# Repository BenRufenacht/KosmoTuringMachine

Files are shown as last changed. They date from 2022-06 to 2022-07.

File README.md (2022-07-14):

# Kosmo Turing Machine

This is the Turing Machine Eurorack module by Tom Whitwell converted into Kosmo format.

<p align="center">
  
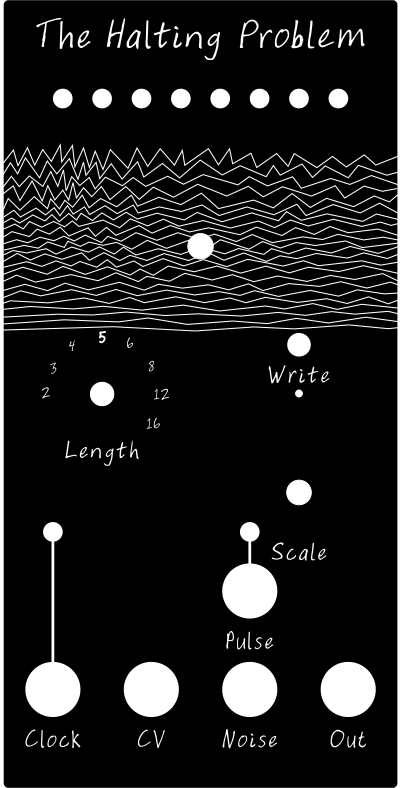
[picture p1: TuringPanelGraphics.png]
  
  
</p>

<p align="center">
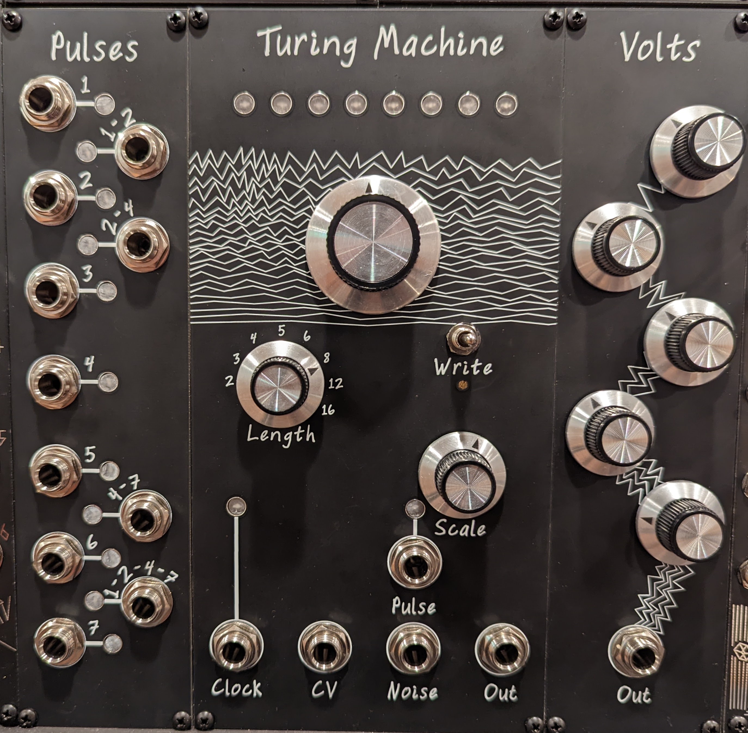
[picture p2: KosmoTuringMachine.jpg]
  
</p>

Here is the description of the module from Tom Whitwell:

Since it was launched in June 2012, the Turing Machine has become one of the most popular Eurorack DIY projects. It is a random looping sequencer that spits out basslines and melodies. It generates strings of random voltages that can be locked into looping sequences. 
These sequences can be allowed to slip, changing gradually over time. This module was inspired by the long history of shift register pseudorandom synth circuits, including the Triadex Muse, Buchla 266 Source of Uncertainly and Grant Richter’s Noisering.

[This video explains how the Turing Machine works.](https://www.youtube.com/watch?v=Le26BIqB8Y8)  

The 2016 revised Turing Machine has many improvements:  
- Rotary loop length switch 
- Pulse out
- Two boards, includes Backpack circuit to drive expanders (compatible with old Music Thing expanders)  
- Easier to build: a larger PCB in the same width, clock and noise circuits are more robust
- Noise level trimmer & reduced voltage in noise circuit to make circuit more robust with different noise transistors 
- Compatible with existing expanders 

[Schematic](https://github.com/TomWhitwell/TuringMachine/blob/master/Collateral/PDF%20Schematics/TuringMachine2_Schematic_May2016.pdf)

Status:   
July 2022 - Boards were manufactured and tested. Updates have been made to the main board and panel, but these updates have not been tested.

License:  
[CC-BY-SA](https://creativecommons.org/licenses/by-sa/3.0/)

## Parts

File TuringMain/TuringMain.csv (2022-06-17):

Source: | C:\Users\Walter\Documents\GitHub\KosmoTuringMachine\TuringMain\TuringMain.kicad_sch
Date: | 6/17/2022 11:51:15 AM
Tool: | Eeschema (6.0.5)
Generator: | C:\Program Files\KiCad\6.0\bin\scripting\plugins/bom_csv_grouped_by_value.py
Component Count: | 108
Individual Components:
Item | Qty | Reference(s) | Value | LibPart | Footprint | Datasheet | SKU | Vendor
 |  | AND_1 | 4081 | TuringBack-eagle-import:4081N | TuringBack:DIL14
 |  | AND_2 | 4081 | TuringBack-eagle-import:4081N | TuringBack:DIL14
 |  | BUFFER1 | 4050 | TuringBack-eagle-import:4050N | TuringBack:DIL16
 |  | BUFFER2 | 4050 | TuringBack-eagle-import:4050N | TuringBack:DIL16
 |  | C1 | 100n | TuringFront-eagle-import:C-EU050-024X044 | TuringFront:C050-024X044
 |  | C2 | 100n | TuringFront-eagle-import:C-EU050-024X044 | TuringFront:C050-024X044
 |  | C3 | 100n | TuringFront-eagle-import:C-EU050-024X044 | TuringFront:C050-024X044
 |  | C4 | 100n | TuringFront-eagle-import:C-EU050-024X044 | TuringFront:C050-024X044
 |  | C5 | 10uf | ao_symbols:CP | ao_tht:CP_Radial_D6.3mm_P2.50mm |  |  | Tayda
 |  | C6 | 10uf | ao_symbols:CP | ao_tht:CP_Radial_D6.3mm_P2.50mm |  |  | Tayda
 |  | C7 | 100n | TuringFront-eagle-import:C-EU050-024X044 | TuringFront:C050-024X044
 |  | C8 | 100n | TuringFront-eagle-import:C-EU050-024X044 | TuringFront:C050-024X044
 |  | C9 | 10n | TuringFront-eagle-import:C-EU050-024X044 | TuringFront:C050-024X044
 |  | C10 | 0.47uf | TuringFront-eagle-import:C-EU050-035X075 | TuringFront:C050-035X075
 |  | C11 | 0.47uf | TuringFront-eagle-import:C-EU050-035X075 | TuringFront:C050-035X075
 |  | C12 | 1n | TuringFront-eagle-import:C-EU050-024X044 | TuringFront:C050-024X044
 |  | C13 | 100n | TuringFront-eagle-import:C-EU050-024X044 | TuringFront:C050-024X044
 |  | C14 | 100n | TuringFront-eagle-import:C-EU050-024X044 | TuringFront:C050-024X044
 |  | C15 | 330pf | TuringFront-eagle-import:C-EU050-024X044 | TuringFront:C050-024X044
 |  | C16 | 100n | TuringFront-eagle-import:C-EU050-024X044 | TuringFront:C050-024X044
 |  | C17 | 1n | TuringFront-eagle-import:C-EU050-024X044 | TuringFront:C050-024X044
 |  | C18 | 0.47uf | TuringFront-eagle-import:C-EU050-035X075 | TuringFront:C050-035X075
 |  | C19 | 100n | TuringFront-eagle-import:C-EU050-024X044 | TuringFront:C050-024X044
 |  | C20 | 1n | TuringFront-eagle-import:C-EU050-024X044 | TuringFront:C050-024X044
 |  | C21 | 100n | TuringFront-eagle-import:C-EU050-024X044 | TuringFront:C050-024X044
 |  | C22 | 100n | TuringFront-eagle-import:C-EU050-024X044 | TuringFront:C050-024X044
 |  | C23 | 1n | TuringFront-eagle-import:C-EU050-024X044 | TuringFront:C050-024X044
 |  | C24 | 1n | TuringFront-eagle-import:C-EU050-024X044 | TuringFront:C050-024X044
 |  | C25 | 1n | TuringFront-eagle-import:C-EU050-024X044 | TuringFront:C050-024X044
 |  | C26 | 100n | TuringFront-eagle-import:C-EU050-024X044 | TuringFront:C050-024X044
 |  | C27 | 100n | TuringFront-eagle-import:C-EU050-024X044 | TuringFront:C050-024X044
 |  | CHANGE1 | 50k | ao_symbols:R_POT | ao_tht:Potentiometer_Alpha_RD901F-40-00D_Single_Vertical_centered | ~ |  | Tayda
 |  | CLK1 | LED5MM | ao_symbols:LED_green | ao_tht:LED_D5.0mm | ~ | A-1553 | Tayda
 |  | CLOCK1 | THONKICONNNEW | ao_symbols:AudioJack2 | ao_tht:Jack_6.35mm_PJ_629HAN | ~ | A-1121 | Tayda
 |  | CV_IN1 | THONKICONNNEW | ao_symbols:AudioJack2 | ao_tht:Jack_6.35mm_PJ_629HAN | ~ | A-1121 | Tayda
 |  | CV_OUT1 | THONKICONNNEW | ao_symbols:AudioJack2 | ao_tht:Jack_6.35mm_PJ_629HAN | ~ | A-1121 | Tayda
 |  | D2 | 1N4148 | TuringFront-eagle-import:SMALL_DIODEDO35-7 | TuringFront:DO35-7
 |  | GATES1 | MA08-2 | Connector_Generic:Conn_02x08_Odd_Even | Connector_IDC:IDC-Header_2x08_P2.54mm_Vertical | ~
 |  | IC1 | TL072P | TuringBack-eagle-import:TL072P | TuringBack:DIL08
 |  | IC2 | 78L09 | ao_symbols:L78L05_TO92 | Package_TO_SOT_THT:TO-92_Inline | http://www.st.com/content/ccc/resource/technical/document/datasheet/15/55/e5/aa/23/5b/43/fd/CD00000446.pdf/files/CD00000446.pdf/jcr:content/translations/en.CD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 | A-176 | Tayda
 |  | IC3 | 78L09 | ao_symbols:L78L05_TO92 | Package_TO_SOT_THT:TO-92_Inline | http://www.st.com/content/ccc/resource/technical/document/datasheet/15/55/e5/aa/23/5b/43/fd/CD00000446.pdf/files/CD00000446.pdf/jcr:content/translations/en.CD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 | A-176 | Tayda
 |  | J1 | Conn_01x10_Male | Connector:Conn_01x10_Male | Connector_PinHeader_2.54mm:PinHeader_1x10_P2.54mm_Vertical | ~
 |  | J2 | Conn_01x10_Female | Connector:Conn_01x10_Female | Connector_PinSocket_2.54mm:PinSocket_1x10_P2.54mm_Vertical | ~
 |  | L1 | BL01RN1A | TuringBack-eagle-import:BL01RN1A | TuringBack:BL01RN1A
 |  | L2 | BL01RN1A | TuringBack-eagle-import:BL01RN1A | TuringBack:BL01RN1A
 |  | LENGTH1 | ALPS-SRBV | TuringFront-eagle-import:ALPS-SRBV | TuringFront:ALPS-SRBV
 |  | NOISE-OUT1 | THONKICONNNEW | ao_symbols:AudioJack2 | ao_tht:Jack_6.35mm_PJ_629HAN | ~ | A-1121 | Tayda
 |  | PULS1 | LED5MM | ao_symbols:LED_green | ao_tht:LED_D5.0mm | ~ | A-1553 | Tayda
 |  | PULSE_OUT1 | THONKICONNNEW | ao_symbols:AudioJack2 | ao_tht:Jack_6.35mm_PJ_629HAN | ~ | A-1121 | Tayda
 |  | PULSES1 | MA08-2 | busboard-cache:Connector_Generic_Conn_02x08_Odd_Even | Connector_IDC:IDC-Header_2x08_P2.54mm_Vertical
 |  | R1 | 2.2k | ao_symbols:R | ao_tht:R_Axial_DIN0207_L6.3mm_D2.5mm_P10.16mm_Horizontal |  |  | Tayda
 |  | R2 | 15k | ao_symbols:R | ao_tht:R_Axial_DIN0207_L6.3mm_D2.5mm_P10.16mm_Horizontal |  |  | Tayda
 |  | R3 | 68k | ao_symbols:R | ao_tht:R_Axial_DIN0207_L6.3mm_D2.5mm_P10.16mm_Horizontal |  |  | Tayda
 |  | R4 | 2.2k | ao_symbols:R | ao_tht:R_Axial_DIN0207_L6.3mm_D2.5mm_P10.16mm_Horizontal |  |  | Tayda
 |  | R5 | 51k | ao_symbols:R | ao_tht:R_Axial_DIN0207_L6.3mm_D2.5mm_P10.16mm_Horizontal |  |  | Tayda
 |  | R6 | 2.2k | ao_symbols:R | ao_tht:R_Axial_DIN0207_L6.3mm_D2.5mm_P10.16mm_Horizontal |  |  | Tayda
 |  | R7 | 470k | ao_symbols:R | ao_tht:R_Axial_DIN0207_L6.3mm_D2.5mm_P10.16mm_Horizontal |  |  | Tayda
 |  | R8 | 2.2k | ao_symbols:R | ao_tht:R_Axial_DIN0207_L6.3mm_D2.5mm_P10.16mm_Horizontal |  |  | Tayda
 |  | R9 | 15k | ao_symbols:R | ao_tht:R_Axial_DIN0207_L6.3mm_D2.5mm_P10.16mm_Horizontal |  |  | Tayda
 |  | R10 | 100k | ao_symbols:R | ao_tht:R_Axial_DIN0207_L6.3mm_D2.5mm_P10.16mm_Horizontal |  |  | Tayda
 |  | R11 | 100k | TuringFront-eagle-import:RESISTOR7MM | ao_tht:R_Axial_DIN0207_L6.3mm_D2.5mm_P10.16mm_Horizontal
 |  | R12 | 10k | ao_symbols:R | ao_tht:R_Axial_DIN0207_L6.3mm_D2.5mm_P10.16mm_Horizontal |  |  | Tayda
 |  | R13 | 2.2k | ao_symbols:R | ao_tht:R_Axial_DIN0207_L6.3mm_D2.5mm_P10.16mm_Horizontal |  |  | Tayda
 |  | R14 | 2.2k | ao_symbols:R | ao_tht:R_Axial_DIN0207_L6.3mm_D2.5mm_P10.16mm_Horizontal |  |  | Tayda
 |  | R15 | 2.2k | ao_symbols:R | ao_tht:R_Axial_DIN0207_L6.3mm_D2.5mm_P10.16mm_Horizontal |  |  | Tayda
 |  | R16 | 2.2k | ao_symbols:R | ao_tht:R_Axial_DIN0207_L6.3mm_D2.5mm_P10.16mm_Horizontal |  |  | Tayda
 |  | R17 | 2.2k | ao_symbols:R | ao_tht:R_Axial_DIN0207_L6.3mm_D2.5mm_P10.16mm_Horizontal |  |  | Tayda
 |  | R18 | 1k | ao_symbols:R | ao_tht:R_Axial_DIN0207_L6.3mm_D2.5mm_P10.16mm_Horizontal |  |  | Tayda
 |  | R19 | 1k | ao_symbols:R | ao_tht:R_Axial_DIN0207_L6.3mm_D2.5mm_P10.16mm_Horizontal |  |  | Tayda
 |  | R20 | 3.3k | ao_symbols:R | ao_tht:R_Axial_DIN0207_L6.3mm_D2.5mm_P10.16mm_Horizontal |  |  | Tayda
 |  | R21 | 2.2k | ao_symbols:R | ao_tht:R_Axial_DIN0207_L6.3mm_D2.5mm_P10.16mm_Horizontal |  |  | Tayda
 |  | R22 | 100k | ao_symbols:R | ao_tht:R_Axial_DIN0207_L6.3mm_D2.5mm_P10.16mm_Horizontal |  |  | Tayda
 |  | R23 | 10k | ao_symbols:R | ao_tht:R_Axial_DIN0207_L6.3mm_D2.5mm_P10.16mm_Horizontal |  |  | Tayda
 |  | R24 | 47k | ao_symbols:R | ao_tht:R_Axial_DIN0207_L6.3mm_D2.5mm_P10.16mm_Horizontal |  |  | Tayda
 |  | R25 | 100k | ao_symbols:R | ao_tht:R_Axial_DIN0207_L6.3mm_D2.5mm_P10.16mm_Horizontal |  |  | Tayda
 |  | R26 | 5.1k | ao_symbols:R | ao_tht:R_Axial_DIN0207_L6.3mm_D2.5mm_P10.16mm_Horizontal |  |  | Tayda
 |  | R27 | 1.6k | ao_symbols:R | ao_tht:R_Axial_DIN0207_L6.3mm_D2.5mm_P10.16mm_Horizontal |  |  | Tayda
 |  | R28 | 1.6k | ao_symbols:R | ao_tht:R_Axial_DIN0207_L6.3mm_D2.5mm_P10.16mm_Horizontal |  |  | Tayda
 |  | R29 | 100k | ao_symbols:R | ao_tht:R_Axial_DIN0207_L6.3mm_D2.5mm_P10.16mm_Horizontal |  |  | Tayda
 |  | R30 | 10k | ao_symbols:R | ao_tht:R_Axial_DIN0207_L6.3mm_D2.5mm_P10.16mm_Horizontal |  |  | Tayda
 |  | R31 | 470k | ao_symbols:R | ao_tht:R_Axial_DIN0207_L6.3mm_D2.5mm_P10.16mm_Horizontal |  |  | Tayda
 |  | R32 | 1k | ao_symbols:R | ao_tht:R_Axial_DIN0207_L6.3mm_D2.5mm_P10.16mm_Horizontal |  |  | Tayda
 |  | R33 | 10k | ao_symbols:R | ao_tht:R_Axial_DIN0207_L6.3mm_D2.5mm_P10.16mm_Horizontal |  |  | Tayda
 |  | R34 | 10k | ao_symbols:R | ao_tht:R_Axial_DIN0207_L6.3mm_D2.5mm_P10.16mm_Horizontal |  |  | Tayda
 |  | R35 | 10k | ao_symbols:R | ao_tht:R_Axial_DIN0207_L6.3mm_D2.5mm_P10.16mm_Horizontal |  |  | Tayda
 |  | R36 | 10k | ao_symbols:R | ao_tht:R_Axial_DIN0207_L6.3mm_D2.5mm_P10.16mm_Horizontal |  |  | Tayda
 |  | R37 | 10k | ao_symbols:R | ao_tht:R_Axial_DIN0207_L6.3mm_D2.5mm_P10.16mm_Horizontal |  |  | Tayda
 |  | R38 | 10k | ao_symbols:R | ao_tht:R_Axial_DIN0207_L6.3mm_D2.5mm_P10.16mm_Horizontal |  |  | Tayda
 |  | R39 | 10k | ao_symbols:R | ao_tht:R_Axial_DIN0207_L6.3mm_D2.5mm_P10.16mm_Horizontal |  |  | Tayda
 |  | SCALE1 | 50k | ao_symbols:R_POT | ao_tht:Potentiometer_Alpha_RD901F-40-00D_Single_Vertical_centered | ~ |  | Tayda
 |  | SHIFTREG_EXT1 | 4015 | TuringBack-eagle-import:4015N | TuringBack:DIL16
 |  | SHIFTREG_MAIN1 | 4015 | TuringBack-eagle-import:4015N | TuringBack:DIL16
 |  | SV1 | 10_PIN_HEADER | ao_symbols:Synth_power_2x5 | ao_tht:Power_Header |  | A-2939 | Tayda
 |  | SWITCH_IC1 | 4016 | TuringBack-eagle-import:4016N | TuringBack:DIL14
 |  | T1 | 2N3904 | ao_symbols:2N3904 | ao_tht:TO-92_Inline_Wide |  | A-111 | Tayda
 |  | TL431 | TL431CLP | Reference_Voltage:TL431LP | Package_TO_SOT_THT:TO-92_Inline | http://www.ti.com/lit/ds/symlink/tl431.pdf
 |  | U1 | TL074_ | TuringFront-eagle-import:TL074_ | TuringFront:DIL14
 |  | U$2 | DAC0800 | TuringFront-eagle-import:DAC0800 | TuringFront:DIL16
 |  | UNK1 | LED5MM | ao_symbols:LED_green | ao_tht:LED_D5.0mm | ~ | A-1553 | Tayda
 |  | UNK2 | LED5MM | ao_symbols:LED_green | ao_tht:LED_D5.0mm | ~ | A-1553 | Tayda
 |  | UNK3 | LED5MM | ao_symbols:LED_green | ao_tht:LED_D5.0mm | ~ | A-1553 | Tayda
 |  | UNK4 | LED5MM | ao_symbols:LED_green | ao_tht:LED_D5.0mm | ~ | A-1553 | Tayda
 |  | UNK5 | LED5MM | ao_symbols:LED_green | ao_tht:LED_D5.0mm | ~ | A-1553 | Tayda
 |  | UNK6 | LED5MM | ao_symbols:LED_green | ao_tht:LED_D5.0mm | ~ | A-1553 | Tayda
 |  | UNK7 | LED5MM | ao_symbols:LED_green | ao_tht:LED_D5.0mm | ~ | A-1553 | Tayda
 |  | UNK8 | LED5MM | ao_symbols:LED_green | ao_tht:LED_D5.0mm | ~ | A-1553 | Tayda
 |  | VR1 | 1m | TuringFront-eagle-import:BOURNS_3362P_TRIMMERP | ao_tht:Potentiometer_Bourns_3296W_Vertical_screw_centered
 |  | WRITE1 | T-80-T-SPDT-ON-OFF-ON | TuringFront-eagle-import:T-80-T-SPDT-ON-OFF-ON | ao_tht:SPDT-toggle-switch-1M-series
Collated Components:
Item | Qty | Reference(s) | Value | LibPart | Footprint | Datasheet | SKU | Vendor
1 | 2 | AND_1, AND_2 | 4081 | TuringBack-eagle-import:4081N | TuringBack:DIL14
2 | 2 | BUFFER1, BUFFER2 | 4050 | TuringBack-eagle-import:4050N | TuringBack:DIL16
3 | 14 | C1, C2, C3, C4, C7, C8, C13, C14, C16, C19, C21, C22, C26, C27 | 100n | TuringFront-eagle-import:C-EU050-024X044 | TuringFront:C050-024X044
4 | 2 | C5, C6 | 10uf | ao_symbols:CP | ao_tht:CP_Radial_D6.3mm_P2.50mm |  |  | Tayda
5 | 1 | C9 | 10n | TuringFront-eagle-import:C-EU050-024X044 | TuringFront:C050-024X044
6 | 3 | C10, C11, C18 | 0.47uf | TuringFront-eagle-import:C-EU050-035X075 | TuringFront:C050-035X075
7 | 6 | C12, C17, C20, C23, C24, C25 | 1n | TuringFront-eagle-import:C-EU050-024X044 | TuringFront:C050-024X044
8 | 1 | C15 | 330pf | TuringFront-eagle-import:C-EU050-024X044 | TuringFront:C050-024X044
9 | 2 | CHANGE1, SCALE1 | 50k | ao_symbols:R_POT | ao_tht:Potentiometer_Alpha_RD901F-40-00D_Single_Vertical_centered | ~ |  | Tayda
10 | 10 | CLK1, PULS1, UNK1, UNK2, UNK3, UNK4, UNK5, UNK6, UNK7, UNK8 | LED5MM | ao_symbols:LED_green | ao_tht:LED_D5.0mm | ~ | A-1553 | Tayda
11 | 5 | CLOCK1, CV_IN1, CV_OUT1, NOISE-OUT1, PULSE_OUT1 | THONKICONNNEW | ao_symbols:AudioJack2 | ao_tht:Jack_6.35mm_PJ_629HAN | ~ | A-1121 | Tayda
12 | 1 | D2 | 1N4148 | TuringFront-eagle-import:SMALL_DIODEDO35-7 | TuringFront:DO35-7
13 | 1 | GATES1 | MA08-2 | Connector_Generic:Conn_02x08_Odd_Even | Connector_IDC:IDC-Header_2x08_P2.54mm_Vertical | ~
14 | 1 | IC1 | TL072P | TuringBack-eagle-import:TL072P | TuringBack:DIL08
15 | 2 | IC2, IC3 | 78L09 | ao_symbols:L78L05_TO92 | Package_TO_SOT_THT:TO-92_Inline | http://www.st.com/content/ccc/resource/technical/document/datasheet/15/55/e5/aa/23/5b/43/fd/CD00000446.pdf/files/CD00000446.pdf/jcr:content/translations/en.CD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 | A-176 | Tayda
16 | 1 | J1 | Conn_01x10_Male | Connector:Conn_01x10_Male | Connector_PinHeader_2.54mm:PinHeader_1x10_P2.54mm_Vertical | ~
17 | 1 | J2 | Conn_01x10_Female | Connector:Conn_01x10_Female | Connector_PinSocket_2.54mm:PinSocket_1x10_P2.54mm_Vertical | ~
18 | 2 | L1, L2 | BL01RN1A | TuringBack-eagle-import:BL01RN1A | TuringBack:BL01RN1A
19 | 1 | LENGTH1 | ALPS-SRBV | TuringFront-eagle-import:ALPS-SRBV | TuringFront:ALPS-SRBV
20 | 1 | PULSES1 | MA08-2 | busboard-cache:Connector_Generic_Conn_02x08_Odd_Even | Connector_IDC:IDC-Header_2x08_P2.54mm_Vertical
21 | 10 | R1, R4, R6, R8, R13, R14, R15, R16, R17, R21 | 2.2k | ao_symbols:R | ao_tht:R_Axial_DIN0207_L6.3mm_D2.5mm_P10.16mm_Horizontal |  |  | Tayda
22 | 2 | R2, R9 | 15k | ao_symbols:R | ao_tht:R_Axial_DIN0207_L6.3mm_D2.5mm_P10.16mm_Horizontal |  |  | Tayda
23 | 1 | R3 | 68k | ao_symbols:R | ao_tht:R_Axial_DIN0207_L6.3mm_D2.5mm_P10.16mm_Horizontal |  |  | Tayda
24 | 1 | R5 | 51k | ao_symbols:R | ao_tht:R_Axial_DIN0207_L6.3mm_D2.5mm_P10.16mm_Horizontal |  |  | Tayda
25 | 2 | R7, R31 | 470k | ao_symbols:R | ao_tht:R_Axial_DIN0207_L6.3mm_D2.5mm_P10.16mm_Horizontal |  |  | Tayda
26 | 4 | R10, R22, R25, R29 | 100k | ao_symbols:R | ao_tht:R_Axial_DIN0207_L6.3mm_D2.5mm_P10.16mm_Horizontal |  |  | Tayda
27 | 1 | R11 | 100k | TuringFront-eagle-import:RESISTOR7MM | ao_tht:R_Axial_DIN0207_L6.3mm_D2.5mm_P10.16mm_Horizontal
28 | 10 | R12, R23, R30, R33, R34, R35, R36, R37, R38, R39 | 10k | ao_symbols:R | ao_tht:R_Axial_DIN0207_L6.3mm_D2.5mm_P10.16mm_Horizontal |  |  | Tayda
29 | 3 | R18, R19, R32 | 1k | ao_symbols:R | ao_tht:R_Axial_DIN0207_L6.3mm_D2.5mm_P10.16mm_Horizontal |  |  | Tayda
30 | 1 | R20 | 3.3k | ao_symbols:R | ao_tht:R_Axial_DIN0207_L6.3mm_D2.5mm_P10.16mm_Horizontal |  |  | Tayda
31 | 1 | R24 | 47k | ao_symbols:R | ao_tht:R_Axial_DIN0207_L6.3mm_D2.5mm_P10.16mm_Horizontal |  |  | Tayda
32 | 1 | R26 | 5.1k | ao_symbols:R | ao_tht:R_Axial_DIN0207_L6.3mm_D2.5mm_P10.16mm_Horizontal |  |  | Tayda
33 | 2 | R27, R28 | 1.6k | ao_symbols:R | ao_tht:R_Axial_DIN0207_L6.3mm_D2.5mm_P10.16mm_Horizontal |  |  | Tayda
34 | 2 | SHIFTREG_EXT1, SHIFTREG_MAIN1 | 4015 | TuringBack-eagle-import:4015N | TuringBack:DIL16
35 | 1 | SV1 | 10_PIN_HEADER | ao_symbols:Synth_power_2x5 | ao_tht:Power_Header |  | A-2939 | Tayda
36 | 1 | SWITCH_IC1 | 4016 | TuringBack-eagle-import:4016N | TuringBack:DIL14
37 | 1 | T1 | 2N3904 | ao_symbols:2N3904 | ao_tht:TO-92_Inline_Wide |  | A-111 | Tayda
38 | 1 | TL431 | TL431CLP | Reference_Voltage:TL431LP | Package_TO_SOT_THT:TO-92_Inline | http://www.ti.com/lit/ds/symlink/tl431.pdf
39 | 1 | U1 | TL074_ | TuringFront-eagle-import:TL074_ | TuringFront:DIL14
40 | 1 | U$2 | DAC0800 | TuringFront-eagle-import:DAC0800 | TuringFront:DIL16
41 | 1 | VR1 | 1m | TuringFront-eagle-import:BOURNS_3362P_TRIMMERP | ao_tht:Potentiometer_Bourns_3296W_Vertical_screw_centered
42 | 1 | WRITE1 | T-80-T-SPDT-ON-OFF-ON | TuringFront-eagle-import:T-80-T-SPDT-ON-OFF-ON | ao_tht:SPDT-toggle-switch-1M-series

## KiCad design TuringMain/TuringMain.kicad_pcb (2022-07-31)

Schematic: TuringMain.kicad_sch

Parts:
AND_1, AND_2: 4081; DIL14
BUFFER1, BUFFER2: 4050; DIL16
C1, C2, C3, C4, C7, C8, C13, C14, C16, C19, C21, C22, C26, C27: 100n; C050-024X044
C5, C6: 10uf; CP_Radial_D6.3mm_P2.50mm
C9: 10n; C050-024X044
C10, C11, C18: 0.47uf; C050-035X075
C12, C17, C20, C23, C24, C25: 1n; C050-024X044
C15: 330pf; C050-024X044
CHANGE1: 50k; Potentiometer_Alpha_RD901F-40-00D_Single_Vertical_centered
CLK1: LED5MM; LED_D5.0mm
CLOCK1: THONKICONNNEW; Jack_6.35mm_PJ_629HAN
CV_IN1: THONKICONNNEW; Jack_6.35mm_PJ_629HAN
CV_OUT1: THONKICONNNEW; Jack_6.35mm_PJ_629HAN
D2: 1N4148; DO35-7
GATES1: MA08-2; IDC-Header_2x08_P2.54mm_Vertical
IC1: TL072P; DIL08
IC2, IC3: 78L09; TO-92_Inline_Wide
J1: Conn_01x10_Male; PinHeader_1x10_P2.54mm_Vertical
J2: Conn_01x10_Female; PinSocket_1x10_P2.54mm_Vertical
L1, L2: BL01RN1A
LENGTH1: ALPS-SRBV
NOISE-OUT1: THONKICONNNEW; Jack_6.35mm_PJ_629HAN
PULS1: LED5MM; LED_D5.0mm
PULSES1: MA08-2; IDC-Header_2x08_P2.54mm_Vertical
PULSE_OUT1: THONKICONNNEW; Jack_6.35mm_PJ_629HAN
R1, R4, R6, R8, R13, R14, R15, R16, R17, R21: 2.2k; R_Axial_DIN0207_L6.3mm_D2.5mm_P10.16mm_Horizontal
R2, R9: 15k; R_Axial_DIN0207_L6.3mm_D2.5mm_P10.16mm_Horizontal
R3: 68k; R_Axial_DIN0207_L6.3mm_D2.5mm_P10.16mm_Horizontal
R5: 51k; R_Axial_DIN0207_L6.3mm_D2.5mm_P10.16mm_Horizontal
R7, R31: 470k; R_Axial_DIN0207_L6.3mm_D2.5mm_P10.16mm_Horizontal
R10, R11, R22, R25, R29: 100k; R_Axial_DIN0207_L6.3mm_D2.5mm_P10.16mm_Horizontal
R12, R23, R30, R33, R34, R35, R36, R37, R38, R39: 10k; R_Axial_DIN0207_L6.3mm_D2.5mm_P10.16mm_Horizontal
R18, R19, R32: 1k; R_Axial_DIN0207_L6.3mm_D2.5mm_P10.16mm_Horizontal
R20: 3.3k; R_Axial_DIN0207_L6.3mm_D2.5mm_P10.16mm_Horizontal
R24: 47k; R_Axial_DIN0207_L6.3mm_D2.5mm_P10.16mm_Horizontal
R26: 5.1k; R_Axial_DIN0207_L6.3mm_D2.5mm_P10.16mm_Horizontal
R27, R28: 1.6k; R_Axial_DIN0207_L6.3mm_D2.5mm_P10.16mm_Horizontal
SCALE1: 50k; Potentiometer_Alpha_RD901F-40-00D_Single_Vertical_centered
SHIFTREG_EXT1: 4015; DIL16
SHIFTREG_MAIN1: 4015; DIL16
SV1: 10_PIN_HEADER; Power_Header
SWITCH_IC1: 4016; DIL14
T1: 2N3904; TO-92_Inline_Wide
TL431: TL431CLP; TO-92_Inline_Wide
U1: TL074_; DIL14
U$2: DAC0800; DIL16
UNK1, UNK2, UNK3, UNK4, UNK5, UNK6, UNK7, UNK8: LED5MM; LED_D5.0mm
VR1: 1m; Potentiometer_Bourns_3296W_Vertical_screw_centered
WRITE1: T-80-T-SPDT-ON-OFF-ON; SPDT-toggle-switch-1M-series

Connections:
/+12V: AND_1.14 (VDD), AND_2.14 (VDD), C1.1, C2.1, C3.1, C4.1, C5.1, C7.2, C13.1, C19.2, C26.2, GATES1.15, GATES1.16, IC1.8 (V+), IC2.3 (VI), IC3.3 (VI), L1.2, PULSES1.15, PULSES1.16, R3.1, R20.1, R23.2, R29.1, R33.2, R34.2, SHIFTREG_EXT1.16 (VDD), SHIFTREG_MAIN1.16 (VDD), SWITCH_IC1.14 (VDD), U1.4 (V+), U$2.13 (V+), WRITE1.1 (O)
/+12V_INLET: L1.1, SV1.9 (+12V), SV1.10 (+12V)
/-12V: C6.2, C8.1, C9.2, C14.2, C27.2, GATES1.11, GATES1.12, IC1.4 (V-), L2.2, PULSES1.11, PULSES1.12, R35.2, U1.11 (V-), U$2.3 (V-)
/-12V_INLET: L2.1, SV1.1 (-12V), SV1.2 (-12V)
/B1: AND_1.1 (I0), BUFFER1.9 (I), LENGTH1.F (6), R38.1, SHIFTREG_MAIN1.2 (QD), U$2.5 (B1-MSB), UNK1.2 (A)
/B2: AND_1.12 (I0), BUFFER1.11 (I), SHIFTREG_MAIN1.11 (QC), U$2.6 (B2), UNK2.2 (A)
/B3: AND_1.5 (I0), BUFFER1.7 (I), LENGTH1.E (5), SHIFTREG_MAIN1.12 (QB), U$2.7 (B3), UNK3.2 (A)
/B4: AND_1.8 (I0), BUFFER1.5 (I), LENGTH1.D (4), SHIFTREG_MAIN1.13 (QA), U$2.8 (B4), UNK4.2 (A)
/B5: AND_2.12 (I0), BUFFER2.11 (I), LENGTH1.C (3), R37.1, SHIFTREG_MAIN1.10 (QD), U$2.9 (B5), UNK5.2 (A)
/B6: AND_2.8 (I0), BUFFER2.9 (I), LENGTH1.B (2), SHIFTREG_MAIN1.3 (QC), U$2.10 (B6), UNK6.2 (A)
/B7: AND_2.5 (I0), BUFFER2.7 (I), LENGTH1.A (1), SHIFTREG_MAIN1.4 (QB), U$2.11 (B7), UNK7.2 (A)
/B8: AND_2.1 (I0), BUFFER2.5 (I), SHIFTREG_MAIN1.5 (QA), U$2.12 (B8-LSB), UNK8.2 (A)
/BUFFCLK: AND_1.2 (I1), AND_1.6 (I1), AND_1.9 (I1), AND_1.13 (I1), BUFFER2.2 (O), PULSES1.9, PULSES1.10
/BUFFCLK2: AND_2.2 (I1), AND_2.6 (I1), AND_2.9 (I1), AND_2.13 (I1), BUFFER1.2 (O), GATES1.9, GATES1.10
/CLOCK: BUFFER1.3 (I), BUFFER2.3 (I), D2.C, R7.1, R12.1, R13.1, SHIFTREG_EXT1.1 (CLK), SHIFTREG_EXT1.9 (CLK), SHIFTREG_MAIN1.1 (CLK), SHIFTREG_MAIN1.9 (CLK)
/CLOCK_IN: J1.2, R2.1
/CV_IN: J1.4, R5.1
/CV_OUT: CV_OUT1.T, J1.8, SCALE1.2
/END_OF_LOOP: LENGTH1.COM (A), LENGTH1.COM2 (A), SWITCH_IC1.1 (A), SWITCH_IC1.5 (C)
/GATE1: BUFFER2.4 (O), GATES1.1
/GATE2: BUFFER2.6 (O), GATES1.2
/GATE3: BUFFER2.10 (O), GATES1.3
/GATE4: BUFFER2.12 (O), GATES1.4
/GATE5: BUFFER1.4 (O), GATES1.5
/GATE6: BUFFER1.6 (O), GATES1.6
/GATE7: BUFFER1.12 (O), GATES1.7
/GATE8: GATES1.8
/LOOP_CTRL: IC1.2 (-IN), R5.2, R22.2, R24.1
/NOISE: C11.2, IC1.5 (+IN), R11.2, R19.2
/NOISE_OUT: J1.6, R19.1
/PULSE1: AND_2.3 (O), BUFFER1.14 (I), PULSES1.1
/PULSE2: AND_2.4 (O), PULSES1.2
/PULSE3: AND_2.10 (O), PULSES1.3
/PULSE4: AND_2.11 (O), PULSES1.4
/PULSE5: AND_1.10 (O), PULSES1.5
/PULSE6: AND_1.4 (O), PULSES1.6
/PULSE7: AND_1.11 (O), PULSES1.7
/PULSE8: AND_1.3 (O), PULSES1.8
/PULSE_OUT: BUFFER1.15 (O), J1.7, R17.1
/START_OF_LOOP: C20.2, R18.2, R36.1, SHIFTREG_MAIN1.7 (D)
/STEP_12: C25.2, LENGTH1.G (7), R39.2, SHIFTREG_EXT1.15 (D)
/STEP_16: LENGTH1.H (8), SHIFTREG_EXT1.2 (QD)
GND: AND_1.7 (VSS), AND_2.7 (VSS), BUFFER1.8 (VSS), BUFFER2.8 (VSS), BUFFER2.14 (I), C1.2, C2.2, C3.2, C4.2, C5.2, C6.1, C7.1, C8.2, C13.2, C14.1, C15.1, C16.1, C19.1, C20.1, C21.1, C22.1, C23.1, C24.1, C25.1, C26.1, C27.1, CLK1.1 (K), CLOCK1.S, CV_IN1.S, CV_OUT1.S, GATES1.13, GATES1.14, IC1.3 (+IN), IC2.2 (GND), IC3.2 (GND), J1.1, J1.10, J2.1, J2.10, NOISE-OUT1.S, PULS1.1 (K), PULSES1.13, PULSES1.14, PULSE_OUT1.S, R1.2, R4.2, R6.2, R8.2, R9.1, R10.1, R11.1, R12.2, R14.1, R15.1, R16.1, R21.1, R27.1, SCALE1.1, SHIFTREG_EXT1.6 (RES), SHIFTREG_EXT1.8 (VSS), SHIFTREG_EXT1.14 (RES), SHIFTREG_MAIN1.6 (RES), SHIFTREG_MAIN1.8 (VSS), SHIFTREG_MAIN1.14 (RES), SV1.3 (GND), SV1.4 (GND), SV1.5 (GND), SV1.6 (GND), SV1.7 (GND), SV1.8 (GND), SWITCH_IC1.3 (B), SWITCH_IC1.7 (VSS), SWITCH_IC1.9 (B), T1.2 (B), TL431.2 (A), U1.3 (+IN), U1.10 (+IN), U1.12 (+IN), U$2.1 (VLC), U$2.2 (IOUT), WRITE1.3 (S)
unnamed: BUFFER1.1 (VDD), C21.2, IC2.1 (VO)
unnamed: BUFFER2.1 (VDD), C22.2, IC3.1 (VO)
unnamed: C9.1, U$2.16 (COMP)
unnamed: C10.1, R30.1
unnamed: C10.2, R29.2, T1.1 (E)
unnamed: C11.1, C12.2, U1.14 (OUT), VR1.2, VR1.3
unnamed: C12.1, R32.1, U1.13 (-IN), VR1.1
unnamed: C15.2, R2.2, R7.2, R10.2, U1.5 (+IN)
unnamed: C16.2, R3.2, R9.2, U1.6 (-IN)
unnamed: C17.1, R26.1, U1.2 (-IN), U$2.4 (IOUTB)
unnamed: C17.2, R26.2, SCALE1.3, U1.1 (OUT)
unnamed: C18.1, R31.1, U1.8 (OUT)
unnamed: C18.2, R32.2
unnamed: C23.2, R37.2, SHIFTREG_MAIN1.15 (D)
unnamed: C24.2, R38.2, SHIFTREG_EXT1.7 (D)
unnamed: CHANGE1.1, R35.1
unnamed: CHANGE1.2, R22.1
unnamed: CHANGE1.3, R23.1
unnamed: CLK1.2 (A), R13.2
unnamed: CLOCK1.T, J2.2
unnamed: CV_IN1.T, J2.4
unnamed: D2.A, U1.7 (OUT)
unnamed: IC1.1 (OUT), IC1.6 (-IN), R24.2
unnamed: IC1.7 (OUT), R25.2
unnamed: J2.6, NOISE-OUT1.T
unnamed: J2.7, PULSE_OUT1.T
unnamed: PULS1.2 (A), R17.2
unnamed: R1.1, UNK8.1 (K)
unnamed: R4.1, UNK7.1 (K)
unnamed: R6.1, UNK6.1 (K)
unnamed: R8.1, UNK5.1 (K)
unnamed: R14.2, UNK4.1 (K)
unnamed: R15.2, UNK3.1 (K)
unnamed: R16.2, UNK2.1 (K)
unnamed: R18.1, WRITE1.2
unnamed: R20.2, R28.2, TL431.1 (REF), TL431.3 (K)
unnamed: R21.2, UNK1.1 (K)
unnamed: R25.1, SWITCH_IC1.6 (C), SWITCH_IC1.13 (C)
unnamed: R27.2, U$2.15 (VREF-)
unnamed: R28.1, U$2.14 (VREF+)
unnamed: R30.2, R31.2, U1.9 (-IN)
unnamed: R33.1, SWITCH_IC1.8 (A), SWITCH_IC1.12 (C)
unnamed: R34.1, SWITCH_IC1.4 (A), SWITCH_IC1.11 (A)
unnamed: R36.2, SWITCH_IC1.2 (B), SWITCH_IC1.10 (B)
unnamed: R39.1, SHIFTREG_EXT1.10 (QD)

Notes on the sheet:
Shift register loop
Length steps: 16 = step_16 12 = step_12 8 = B1 6 = B3 5 = B4 4 = B5 3 = B6 2 = B7
Randomised invert/loop switching
/Users/aash/Dropbox/Electronics/~{MODULAR/design/logo} copy.bmp
DAC
NB: Bit numbers are reversed at this point: Bit8 = first bit (left hand LED on main module) becomes Pulse1 (Top output on expanders)
Clock input
Noise Generator

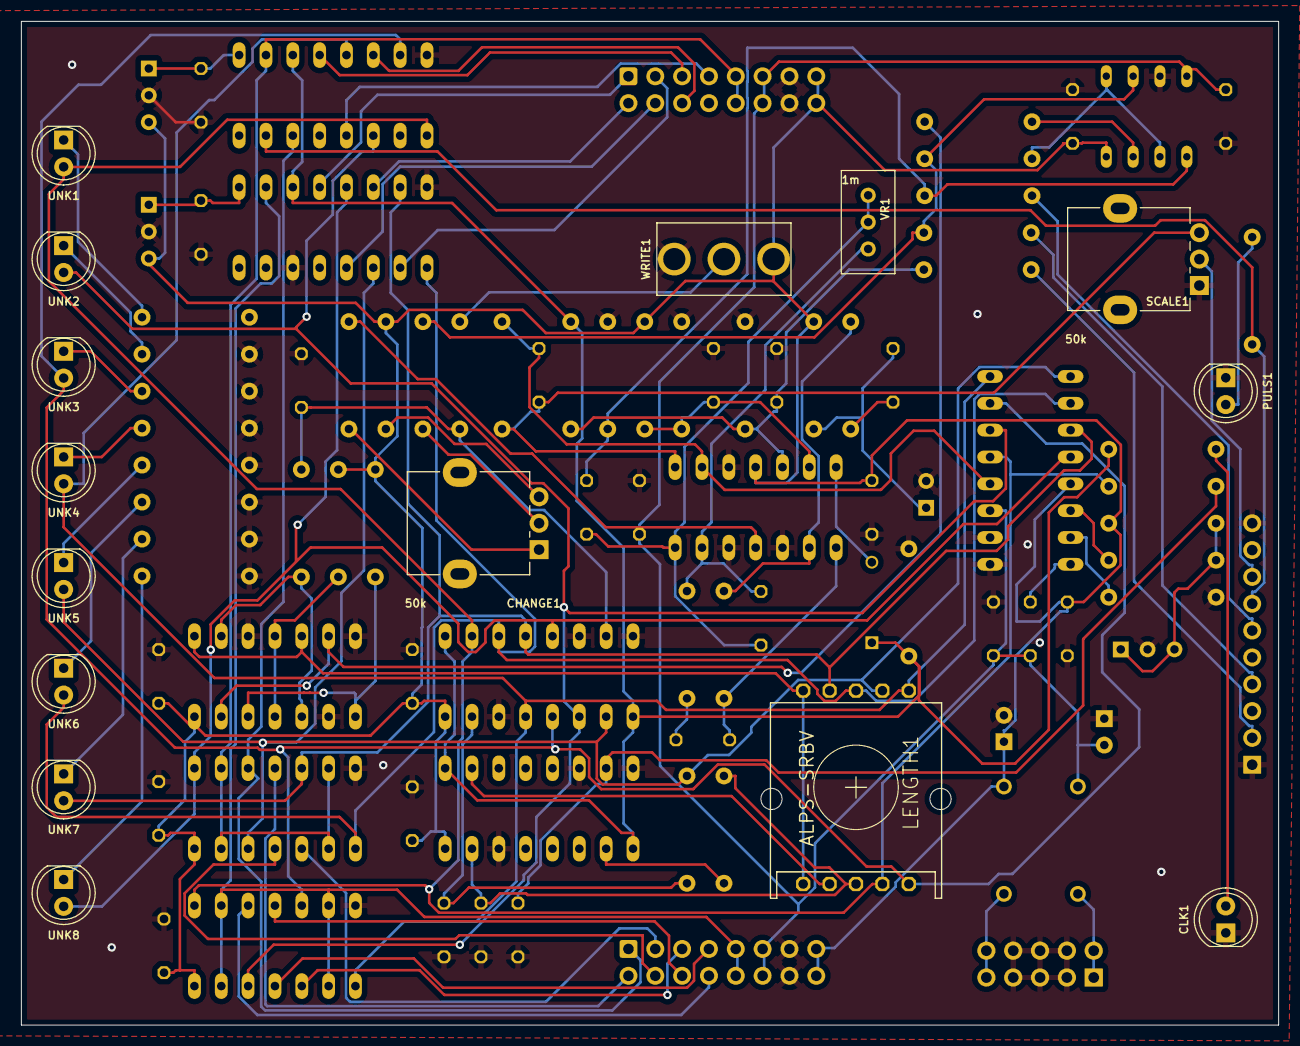
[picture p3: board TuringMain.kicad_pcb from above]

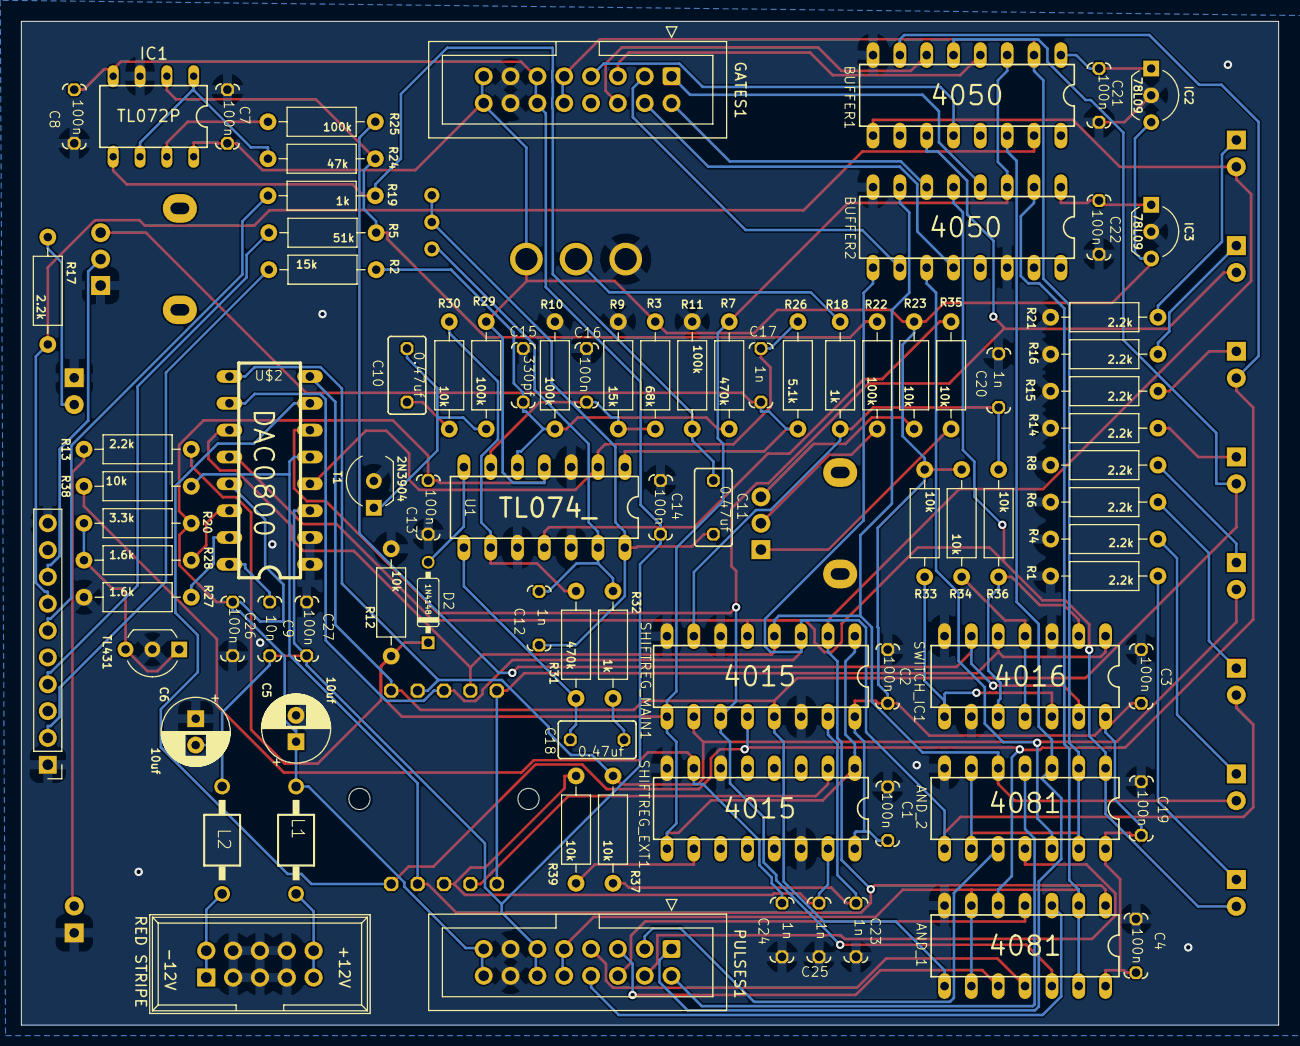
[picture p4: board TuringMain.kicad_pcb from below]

Board: 2 copper layers, 119.0 x 95.0 mm, 102 parts (87 on the bottom side), 83 nets.

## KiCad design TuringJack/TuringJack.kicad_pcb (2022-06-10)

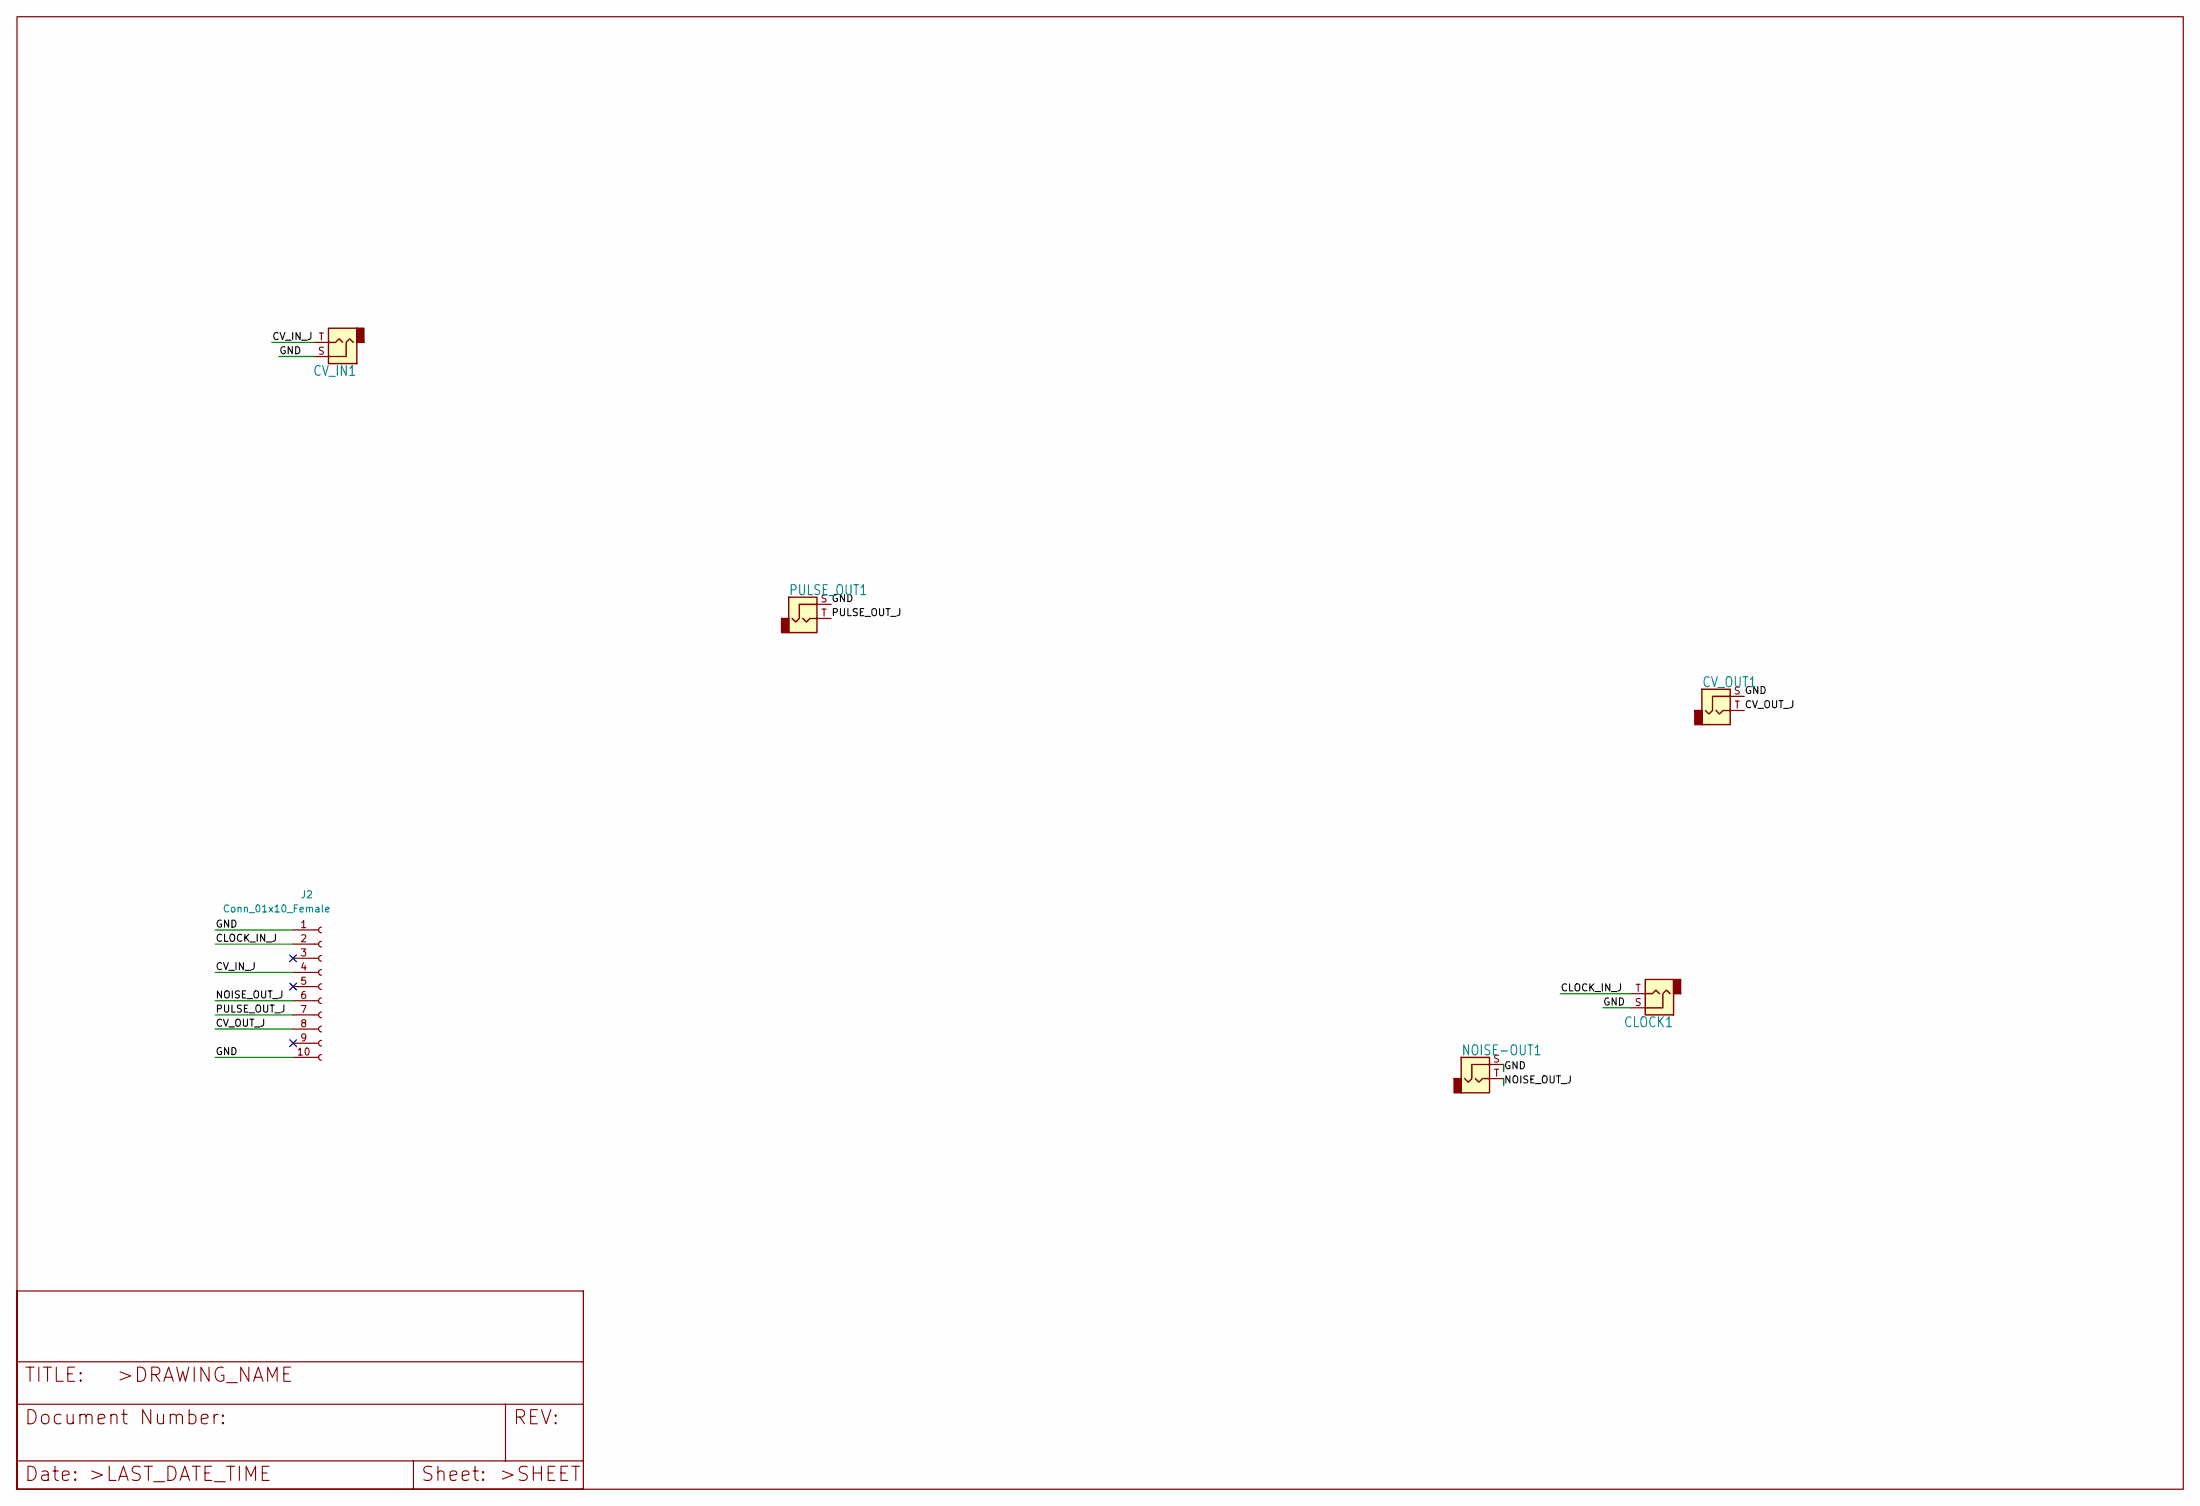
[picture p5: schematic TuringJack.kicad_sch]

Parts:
CLOCK1: THONKICONNNEW; Jack_6.35mm_PJ_629HAN
CV_IN1: THONKICONNNEW; Jack_6.35mm_PJ_629HAN
CV_OUT1: THONKICONNNEW; Jack_6.35mm_PJ_629HAN
J2: Conn_01x10_Female; PinSocket_1x10_P2.54mm_Vertical
NOISE-OUT1: THONKICONNNEW; Jack_6.35mm_PJ_629HAN
PULSE_OUT1: THONKICONNNEW; Jack_6.35mm_PJ_629HAN

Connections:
/CLOCK_IN_J: CLOCK1.T, J2.2
/CV_IN_J: CV_IN1.T, J2.4
/CV_OUT_J: CV_OUT1.T, J2.8
/GND: CLOCK1.S, CV_IN1.S, CV_OUT1.S, J2.1, J2.10, NOISE-OUT1.S, PULSE_OUT1.S
/NOISE_OUT_J: J2.6, NOISE-OUT1.T
/PULSE_OUT_J: J2.7, PULSE_OUT1.T

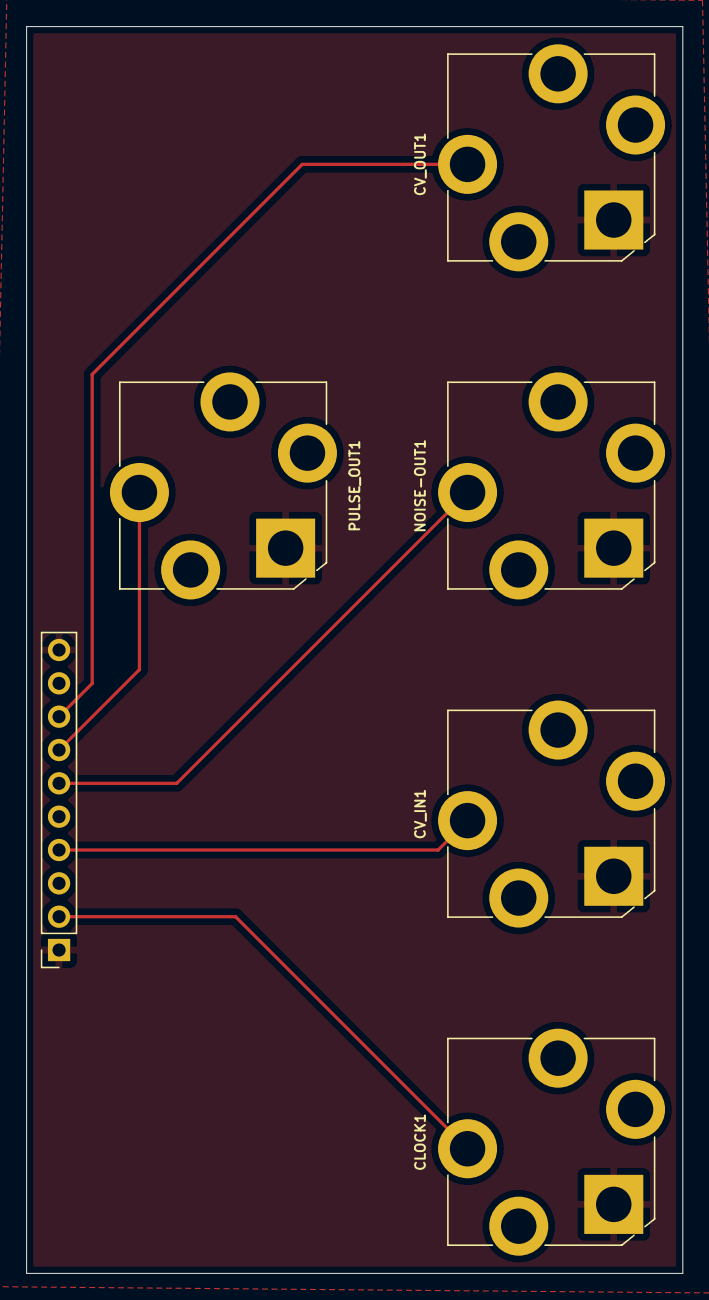
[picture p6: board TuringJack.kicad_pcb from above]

Board: 2 copper layers, 50.0 x 95.0 mm, 6 parts (0 on the bottom side), 6 nets.

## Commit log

2022-06-05 Initial Upload
    [TuringJack.kicad_pcb, TuringJack.kicad_sch, TuringMain.dsn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]
2022-06-05 Main Board Updates
    Fixed GND errors and flipped expansion headers to back of the board
    [TuringMain.kicad_pcb]
2022-06-09 Updated Panel Graphics
    [TuringPanel.kicad_pcb]
2022-06-10 Manufacturing Updates
    [TuringJack-B_Cu.gbr, TuringJack-B_Mask.gbr, TuringJack-B_Paste.gbr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]
2022-07-14 Manufacturing Updates
    Rotary Switch Panel Drill Corrected
    Panel Graphics Changed (Name changed from Turing Machine to The Halting Problem)
    Updated silkscreen on mainboard with circuit corrections and component values.
    [TuringMain-B_Cu.gbr, TuringMain-B_Mask.gbr, TuringMain-B_Paste.gbr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]
2022-07-14 Gerber zip
2022-07-31 Minor Main Board updates
    [TuringMain-B_Cu.gbr, TuringMain-B_Mask.gbr, TuringMain-B_Paste.gbr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]

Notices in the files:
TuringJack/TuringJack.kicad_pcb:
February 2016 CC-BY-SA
